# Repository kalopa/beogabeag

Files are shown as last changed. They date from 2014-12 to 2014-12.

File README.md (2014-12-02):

beogabeag
=========

Open Source software and mechanical elements for the Beoga Beag autonomous sailboat.
Contains the boat design files and documentation.

You can get more information on the boat and the Microtransat race on our blog:

http://blog.beogabeag.org/

I will add the DelftShip design files and some of the other CAD data for the various hulls, as we go.

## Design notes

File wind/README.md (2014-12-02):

Masthead Wind Direction Indicator
=================================

These are the SCad files for building the masthead wind direction
indicator and the tricolour light.

The unit is in three parts. The main component has a top end-cap with a
5mm hole for the wind direction shaft. The wind direction arrow should
be a 4mm solid bronze shaft (solid) with a flat edge on one side for
the twin potentiometers. Just underneath the end cap is a 624 sealed
ball bearing. After this is a shaft collar, which prevents the shaft
from being pulled out of the unit. Under this are a pair of 2K5 low
torque potentiometers, which are mounted "out of phase." One is mounted
upside down and on top of the other. Make sure that the two pots are
180 degrees out of phase also so that the three pins on one are on the
opposite side to the three pins on the other. This means that one or
other pot will always provide a reading. This unit also houses the three
LEDs, which should be red, green and white. You will notice a small
arrow which indicates where the front of the unit is. This component is in
the file wdi_top.scad.

The pots are mounted in the second printable component, which is in
the file wdi_mount.scad. It also has an end-cap which seals the unit.

The third component is the mast base. It is in the file wdi_base.scad. The
base fits over an 8mm carbon fibre tube, and can be glued or epoxied
in place.

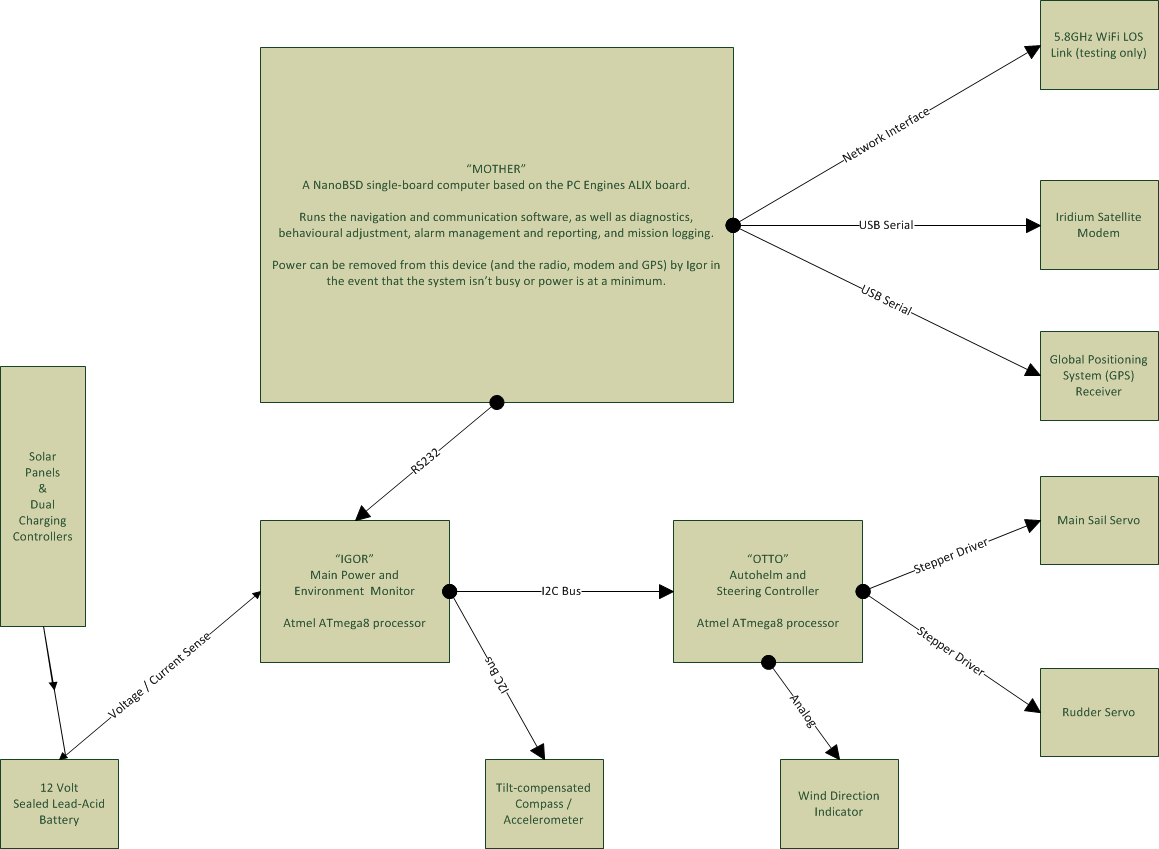
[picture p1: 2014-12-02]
architecture.png

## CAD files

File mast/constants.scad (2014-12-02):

/*
 * Written by Dermot Tynan, Kalopa Research.
 * GPLv2.
 *
 * This file has all the constants for the OpenWing sail.
 *
 * All dimensions are in mm.
 */
wall_thickness = 3;

cf_mast_outer_dia = 20.85;
cf_mast_inner_dia = 17.90;
cf_mast_insert_len = 20;

mast_cap_dia = 24;
mast_cap_height = 16;
mast_base_x = 24;
mast_base_y = 24;
mast_base_height = 12;
mast_base_grip_off = 8;
mast_base_grip_dia = 3.2;

gooseneck_height = 24;
gooseneck_len = 20;
gooseneck_barrel_dia = 11;
gooseplate_width = 26;

kicker_ring_dia = 18;

attach_pin_dia = 6;
washer_thickness = 0.8;
rigging_line_dia = 4;

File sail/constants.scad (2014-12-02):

/*
 * Written by Dermot Tynan, Kalopa Research.
 * GPLv2.
 *
 * This file has all the constants for the OpenWing sail.
 *
 * All dimensions are in mm.
 */

bearing_inner_radius = 4.0;
bearing_outer_radius = 11.0 * 1.02;
bearing_height = 7.0;

mast_clearance_radius = 5.0;

a_section_chord = 133.0;

le_tube_radius = 4.0 * 1.0625;

te_depth = 6.4;
te_width = 20.0;

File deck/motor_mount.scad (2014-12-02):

module motor_screw()
{
	translate([0, 31/2, 50])
		cylinder(r = 3.2/2, h = 10, center = true);
}

module motor()
{
	mlen = 94;
	union() {
		cylinder(r = 37/2, h = mlen, center = true);
		translate([0, 7, 3 + mlen/2]) cylinder(r = 6.4, h = 10, center = true);
		rotate(a = [0, 0, 90]) motor_screw();
		rotate(a = [0, 0, 270]) motor_screw();
	}
}

module motor_wall(t, l, h)
{
	intersection() {
		cube([t, l, h], center = true);
		translate([0, -l/3, -h/5])
			rotate(a = [-45, 0, 0])
				cube([t, l, h], center = true);
	}
}

module motor_mount()
{
	thickness = 6;
	length = 90;
	height = 40;
	width = 50;
	difference() {
		union()  {
			cube([width, length, thickness], center = true);
			translate([0, -(length - thickness)/2, (height + thickness)/2])
				cube([width, thickness, height], center = true);
			translate([-(width - thickness)/2, 0, (height + thickness)/2])
				motor_wall(thickness, length, height);
			translate([(width - thickness)/2, 0, (height + thickness)/2])
				motor_wall(thickness, length, height);
		}
		translate([0, 9, 37/2 + thickness/2 + 1])
			rotate(a = [90, 180, 0]) motor();
		translate([width/2 - thickness - 5, length/2 - thickness - 5, 0])
			cylinder(r = 4.5/2, h = thickness + 2, center = true);
		translate([-(width/2 - thickness - 5), length/2 - thickness - 5, 0])
			cylinder(r = 4.5/2, h = thickness + 2, center = true);
		translate([width/2 - thickness - 5, 0, 0])
			cylinder(r = 4.5/2, h = thickness + 2, center = true);
		translate([-(width/2 - thickness - 5), 0, 0])
			cylinder(r = 4.5/2, h = thickness + 2, center = true);
		translate([width/2 - thickness - 5, -(length/2 - thickness - 5), 0])
			cylinder(r = 4.5/2, h = thickness + 2, center = true);
		translate([-(width/2 - thickness - 5), -(length/2 - thickness - 5), 0])
			cylinder(r = 4.5/2, h = thickness + 2, center = true);
	}
}

motor_mount();

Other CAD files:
deck/stepdriver_box.scad
deck/antenna_base.scad
deck/gopro_mount.scad
deck/keel_plate.scad
deck/moconbox.scad
deck/moconbox2.scad
deck/moconlid.scad
deck/psu_box.scad
deck/ruddercover.scad
deck/rudhouse.scad
deck/sailcover.scad
deck/sgs_plate.scad
deck/stepper_box.scad
deck/wheel_collar.scad
gears/rudder_big_gear.scad
gears/rudder_small_gear.scad
gears/sail_winch.scad
mast/gooseneck.scad
mast/kicker.scad
mast/mastbase.scad
mast/masthead.scad
parts/buttress.scad
parts/nema17.scad
parts/posts_standoffs.scad
parts/screw_tab.scad
parts/uswitch.scad
sail/hinge.scad
sail/mast1.scad
sail/mast2.scad
sail/mast3.scad
sail/mast_step.scad
sail/naca0009.scad
sail/naca0018.scad
sail/strutjig.scad
sail/wing_assy.scad
wind/assembly.scad
wind/base.scad
wind/capplate.scad
wind/common.scad
wind/mount.scad
wind/rotary.scad
wind/top.scad
wind/wdi_housing.scad
wind/windcap.scad

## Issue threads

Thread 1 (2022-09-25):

Which delftship software is used?

froussel, 2022-09-25:
Hello,

Which delftship software is used?
I have an old version 3.20 but it does not open.

 If you used freeship new version we would be perfectly in open source
https://sourceforge.net/projects/freeship/

Openscad : perfect but freecad is now very good except that I don't know how to use a file from freeship to open it in freecad in order to have a shell with a defined thickness :-((
Today printing a mold in 3D printing saves a lot of work!
https://www.youtube.com/watch?v=YRqQCbzVkN8

I continue to explore the site...

dtynan, 2022-09-25:
That chined hull was designed in about 2013 so whatever version was prominent, back then. However, I wouldn't use that design again for a couple of reasons. Firstly, I didn't like the shape of it in Delftship (due to my inexperience) so I doubled the beam and the draft and the actual hull is way too stubby. I should have left them alone. Secondly, I switched to Paul Miller's MegaMOOP design which is not a chined hull and is a proven design. He did a version of the hull at the full 2.4m LOA as I decided against using a 1.2m design like Hull #1 was. You can find his designs online.

If you really want it, I can dig out the old Delftship version, but I suspect I don't even have the computer any more.

Interesting you should mention FreeCAD. I just received my copy of "Getting started with FreeCAD" (or a similar title) but I haven't started using it yet. Generally I prefer parametric design rather than agonizing over whether or not I've moved the mouse by the exact amount. I have struggled with Fusion 360 too and am looking forward to seeing if FreeCAD solves my issues with WYSIWYG CAD.

I struggled to convert DXF files in order to get a table of offsets, too. I generally go the "plywood stations" route and then cover in balsa, followed by fibreglass on both sides of the balsa - cold moulding, in other words. I remove every second station and epoxy-coat the remaining ones. I foam-fill compartments which don't have electronics or keel bolt access.

Thanks for the interest, and the reminder to start that FreeCAD book!!

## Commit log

2014-12-02 OpenSCAD files for the physical design.
    Added a lot of the mock-up and template SCAD files for various
    elements of the boat. I will clean up this lot at a later stage.
    [antenna_base.scad, assembly.scad, base.scad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]
2014-12-02 Added the DelftShip CAD files for the hull.
